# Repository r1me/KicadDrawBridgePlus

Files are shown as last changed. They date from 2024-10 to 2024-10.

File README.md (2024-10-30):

# KicadDrawBridgePlus
PCB design I've made for the DrawBridge Plus! project by Robert Smith. Based on DrawBridge Plus! schematic.
Visit author's page for more information about the project: http://amiga.robsmithdev.co.uk/

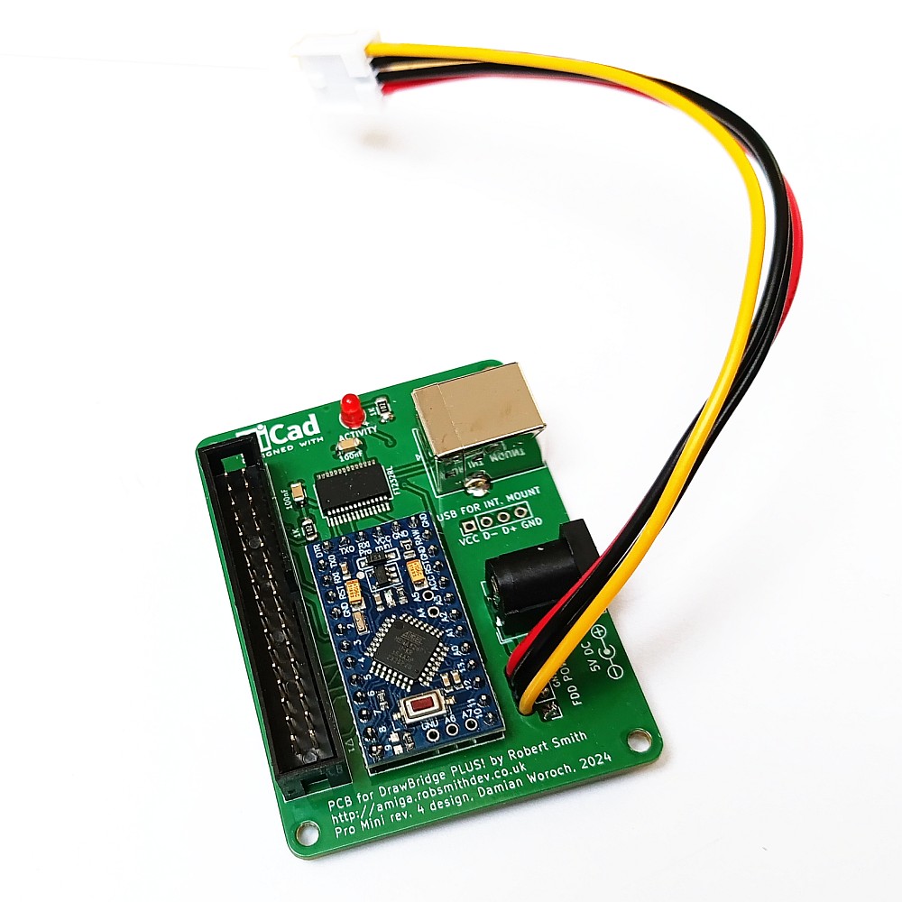
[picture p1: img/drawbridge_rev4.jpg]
Rev4 soldered board


3D case: https://www.thingiverse.com/thing:5342990
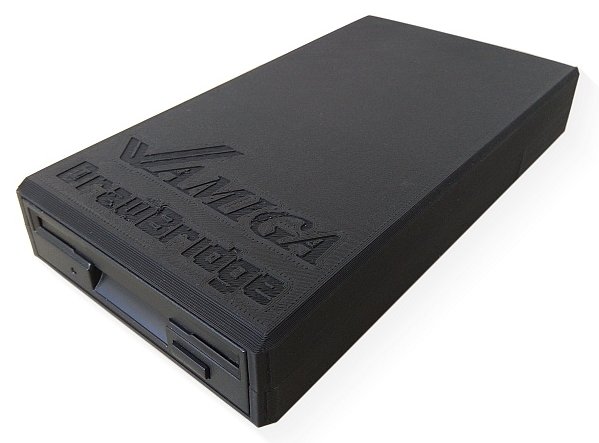
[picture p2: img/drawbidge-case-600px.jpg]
DrawBridge in a 3D printed case


## Changelog

Rev. 4:
* remove +12V socket, 95% of drives are powered with +5V only
* added pin header for mounting DrawBridge in a PC case (internal USB)

Rev. 3:  
* added floppy power cable relief  
* changed resistors size from 0805 to 1206 for easier assembly  

## FT232 note  
Watch out for fake FT232 chips, buy them only from good known source. With fake chips, a read transfer test will fail, also making disk->SCP read unstable.

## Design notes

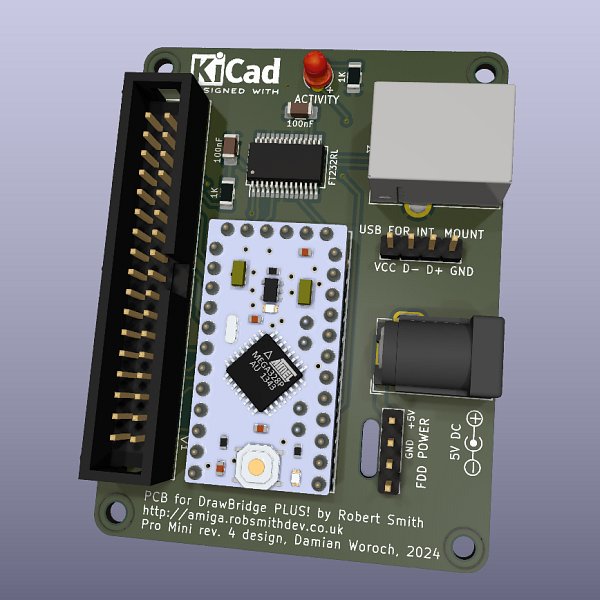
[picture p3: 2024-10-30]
img/drawbridge_rev4_render.jpg

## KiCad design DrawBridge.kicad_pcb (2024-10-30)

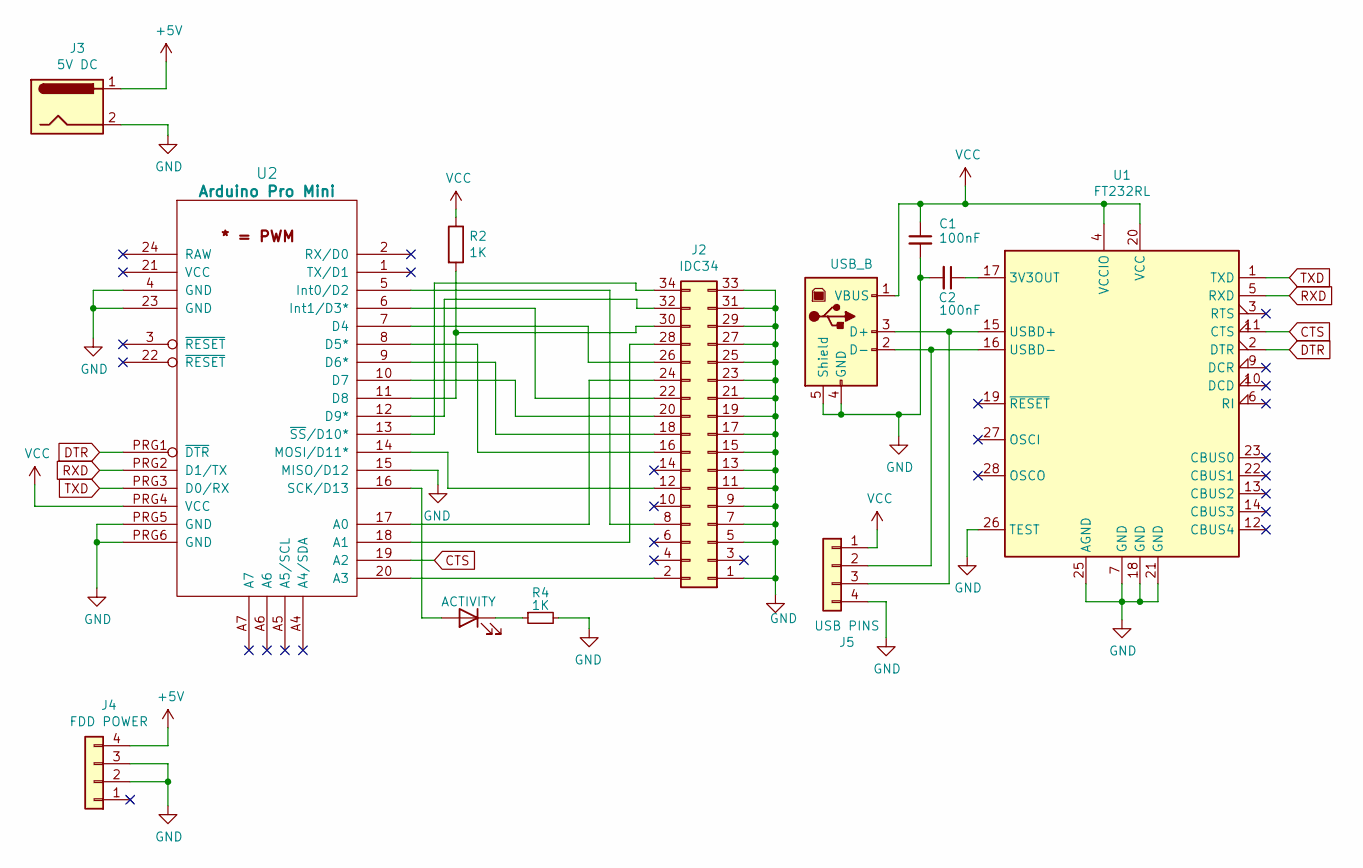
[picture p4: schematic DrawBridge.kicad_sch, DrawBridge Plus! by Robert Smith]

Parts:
C1, C2: 100nF; C_1206_3216Metric_Pad1.33x1.80mm_HandSolder
D2: ACTIVITY; LED_D3.0mm_FlatTop
J1: USB_B; USB_B_OST_USB-B1HSxx_Horizontal
J2: IDC34; IDC-Header_2x17_P2.54mm_Vertical
J3: 5V DC; BarrelJack_Wuerth_6941xx301002
J4: FDD POWER; PinHeader_1x04_P2.54mm_Vertical
J5: USB PINS; PinHeader_1x04_P2.54mm_Vertical
R2, R4: 1K; R_1206_3216Metric_Pad1.30x1.75mm_HandSolder
U1: FT232RL; SSOP-28_5.3x10.2mm_P0.65mm
U2: Arduino Pro Mini; ARDUINO_Pro-ADFRW

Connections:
+5V: J3.1, J4.4
CTS: U1.11 (CTS), U2.19 (A2)
DTR: U1.2 (DTR), U2.PRG1 (~DTR)
GND: C1.2, C2.2, J1.4 (GND), J1.5 (Shield), J2.1, J2.5, J2.7, J2.9, J2.11, J2.13, J2.15, J2.17, J2.19, J2.21, J2.23, J2.25, J2.27, J2.29, J2.31, J2.33, J3.2, J4.2, J4.3, J5.4, R4.2, U1.7 (GND), U1.18 (GND), U1.21 (GND), U1.25 (AGND), U1.26 (TEST), U2.4 (GND), U2.15 (MISO/D12), U2.23 (GND), U2.PRG5 (GND), U2.PRG6 (GND)
unnamed: D2.2 (A), U2.16 (SCK/D13)
unnamed: D2.1 (K), R4.1
unnamed: J1.3 (D+), J5.3, U1.15 (USBD+)
unnamed: J1.2 (D-), J5.2, U1.16 (USBD-)
unnamed: J2.2, U2.20 (A3)
unnamed: J2.8, U2.5 (Int0/D2)
unnamed: J2.12, U2.14 (MOSI/D11*)
unnamed: J2.16, U2.8 (D5*)
unnamed: J2.18, U2.9 (D6*)
unnamed: J2.20, U2.10 (D7)
unnamed: J2.22, U2.6 (Int1/D3*)
unnamed: J2.24, U2.17 (A0)
unnamed: J2.26, U2.7 (D4)
unnamed: J2.28, U2.18 (A1)
unnamed: J2.30, R2.2, U2.11 (D8)
unnamed: J2.32, U2.12 (D9*)
unnamed: J2.34, U2.13 (~SS/D10*)
unnamed: C2.1, U1.17 (3V3OUT)
RXD: U1.5 (RXD), U2.PRG2 (D1/TX)
TXD: U1.1 (TXD), U2.PRG3 (D0/RX)
VCC: C1.1, J1.1 (VBUS), J5.1, R2.1, U1.4 (VCCIO), U1.20 (VCC), U2.PRG4 (VCC)

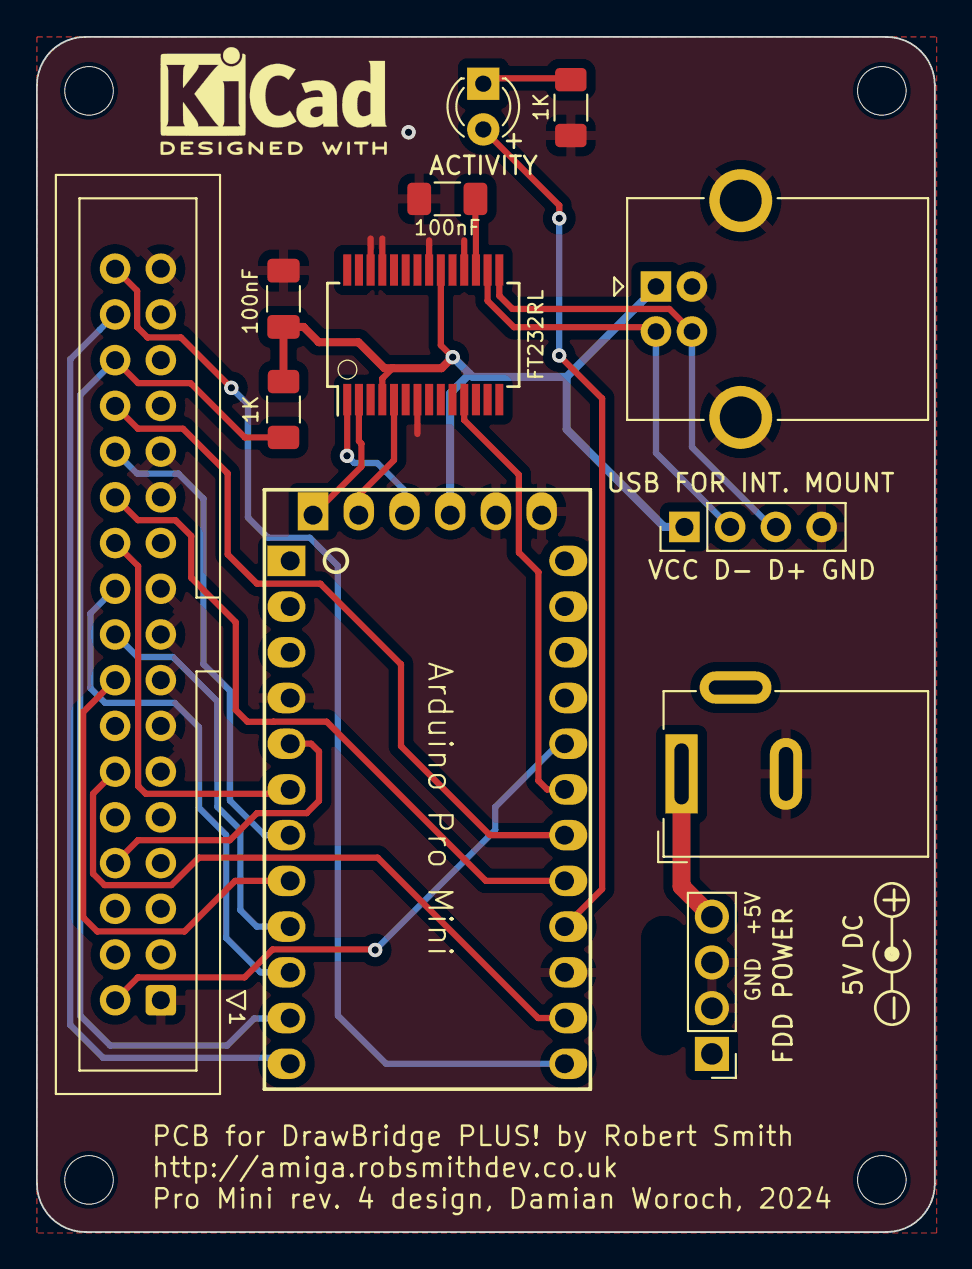
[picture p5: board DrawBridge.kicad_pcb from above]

Board: 2 copper layers, 49.9 x 66.4 mm, 12 parts (0 on the bottom side), 25 nets.

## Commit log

2022-12-01 Upload project files
    [DrawBridge.kicad_pcb, DrawBridge.kicad_sch]
2023-01-21 Increase holes for power cable relief
    rev 3b
    [DrawBridge.kicad_pcb]
2024-10-30 Rev 4
    [DrawBridge.kicad_pcb, DrawBridge.kicad_sch]
